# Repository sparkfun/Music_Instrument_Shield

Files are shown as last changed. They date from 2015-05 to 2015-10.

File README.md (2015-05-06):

SparkFun Music Instrument Shield
========================================

SparkFun Music Instrument Shield

[*SparkFun Music Instrument Shield (DEV-10587)*](https://www.sparkfun.com/products/10587)

The SparkFun Musical Instrument Shield is an easy way to add great sounding MIDI sound to your next Arduino project. 
This board is built around the VS1053 MP3 and MIDI codec IC, wired in MIDI mode. 
Simply connect a speaker/stereo/pair of headphones to the 1/8" stereo jack on the shield and pass the proper serial commands to the IC and you’ll be playing music in no time!

Repository Contents
-------------------

* **/Firmware** - Example code 
* **/Hardware** - Eagle design files (.brd, .sch)
* **/Production** - Production panel files (.brd)

Documentation
--------------
* **[Hookup Guide](https://www.sparkfun.com/tutorials/302)** - Basic hookup guide for the Music Instrument Shield.
* **[SparkFun Fritzing repo](https://github.com/sparkfun/Fritzing_Parts)** - Fritzing diagrams for SparkFun products.
* **[SparkFun 3D Model repo](https://github.com/sparkfun/3D_Models)** - 3D models of SparkFun products. 

License Information
-------------------
This product is _**open source**_! 

The **hardware** is released under [Creative Commons ShareAlike 4.0 International](https://creativecommons.org/licenses/by-sa/4.0/).

The **code** is beerware; if you see me (or any other SparkFun employee) at the local, and you've found our code helpful, please buy us a round!

Please use, reuse, and modify these files as you see fit. Please maintain attribution to SparkFun Electronics and release anything derivative under the same license.

Distributed as-is; no warranty is given.

- Your friends at SparkFun.

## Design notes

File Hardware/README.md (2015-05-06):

SparkFun <PRODUCT NAME> Design Files
=====================================

The .sch and .brd files hare are Eagle CAD schematic and PCB design files from SparkFun Electronics.
A freeware version of Eagle can be found [here](http://www.cadsoftusa.com/download-eagle/freeware/). 

License
---------
This product is open source! 
The hardware is released under [Creative Commons ShareAlike 4.0 International](https://creativecommons.org/licenses/by-sa/4.0/).

Please use, reuse, and modify these files as you see fit. Please maintain attribution to SparkFun Electronics and release anything derivative under the same license.

Distributed as-is; no warranty is given.

- Your friends at SparkFun.

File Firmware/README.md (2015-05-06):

SparkFun Music Instrument Firmware
===================================

* **SparkFunMusicInstrument** - Arduino example
    * Demos the MIDI instrument functionality of the Music Instrument Shield.

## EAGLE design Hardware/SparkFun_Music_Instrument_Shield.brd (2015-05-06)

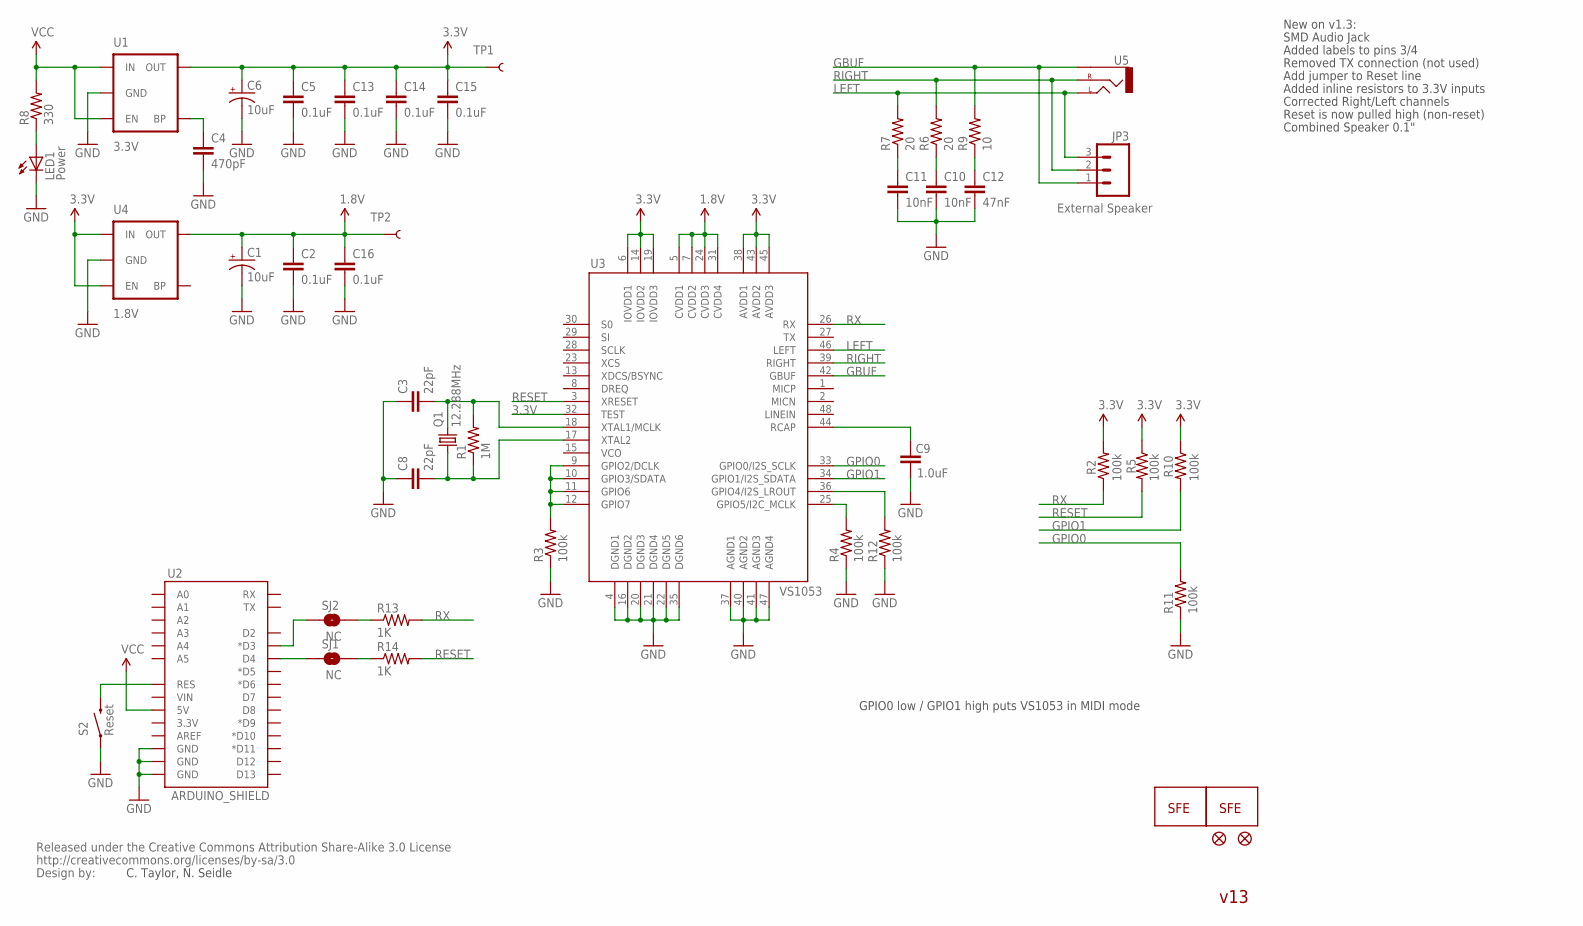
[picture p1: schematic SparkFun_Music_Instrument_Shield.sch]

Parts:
C1, C6: 10uF; EIA3216
C2, C5, C13, C14, C15, C16: 0.1uF; 0402-CAP
C3, C8: 22pF; 0402-CAP
C4: 470pF; 0402-CAP
C9: 1.0uF; 0402-CAP
C10, C11: 10nF; 0402-CAP
C12: 47nF; 0402-CAP
JP3: External Speaker; 1X03
LED1: Power; LED-0603
Q1: 12.288MHz; CRYSTAL-SMD-5X3
R1: 1M; 0402-RES
R2, R3, R4, R5, R10, R11, R12: 100k; 0402-RES
R6, R7: 20; 0402-RES
R8: 330; 0402-RES
R9: 10; 0402-RES
R13, R14: 1K; 0402-RES
S2: Reset; TACTILE_SWITCH_SMD
SJ1, SJ2: NC; SJ_2S-TRACE
TP1, TP2: TEST-POINT3X5; PAD.03X.05
U1: 3.3V; SOT23-5
U2: ARDUINO_SHIELD; DUEMILANOVE_SHIELD
U3: VS1053; LQFP-48
U4: 1.8V; SC70
U5: AUDIO-JACKSMD2; AUDIO-JACK-3.5MM-SMD
U$3: CREATIVE_COMMONS
U$4, U$5: FIDUCIAL1X2; FIDUCIAL-1X2
U$7, U$8: LOGO-SFENEW; SFE-NEW-WEBLOGO

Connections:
1.8V: C1.A (+), C2.1, C16.1, TP2.P$1, U3.5 (CVDD1), U3.7 (CVDD2), U3.24 (CVDD3), U3.31 (CVDD4), U4.5 (OUT)
3.3V: C5.1, C6.A (+), C13.1, C14.1, C15.1, R2.2, R5.1, R10.1, TP1.P$1, U1.5 (OUT), U3.6 (IOVDD1), U3.14 (IOVDD2), U3.19 (IOVDD3), U3.32 (TEST), U3.38 (AVDD1), U3.43 (AVDD2), U3.45 (AVDD3), U4.1 (IN), U4.3 (EN)
ARST: S2.3 (2), U2.RES
G1: R3.2, U3.9 (GPIO2/DCLK), U3.10 (GPIO3/SDATA), U3.11 (GPIO6), U3.12 (GPIO7)
G2: R4.2, U3.25 (GPIO5/I2C_MCLK)
GBUF: JP3.1, R9.2, U3.42 (GBUF), U5.SLEEVE
GND: C1.C (-), C2.2, C3.1, C4.2, C5.2, C6.C (-), C8.1, C9.1, C10.2, C11.2, C12.2, C13.2, C14.2, C15.2, C16.2, LED1.C, R3.1, R4.1, R11.1, R12.1, S2.1, U1.2 (GND), U2.GND@0 (GND), U2.GND@1 (GND), U2.GND@2 (GND), U3.4 (DGND1), U3.16 (DGND2), U3.20 (DGND3), U3.21 (DGND4), U3.22 (DGND5), U3.35 (DGND6), U3.37 (AGND1), U3.40 (AGND2), U3.41 (AGND3), U3.47 (AGND4), U4.2 (GND)
GPIO0: R11.2, U3.33 (GPIO0/I2S_SCLK)
GPIO1: R10.2, U3.34 (GPIO1/I2S_SDATA)
LEFT: JP3.3, R7.2, U3.46 (LEFT), U5.TIP (LEFT)
unnamed: C9.2, U3.44 (RCAP)
unnamed: C12.1, R9.1
unnamed: C10.1, R6.1
unnamed: C11.1, R7.1
unnamed: LED1.A, R8.1
unnamed: SJ1.1, U2.D4
unnamed: R13.1, SJ2.2
unnamed: C3.2, Q1.3 (2), R1.2, U3.18 (XTAL1/MCLK)
unnamed: C8.2, Q1.1, R1.1, U3.17 (XTAL2)
unnamed: R14.1, SJ1.2
unnamed: SJ2.1, U2.D3 (*D3)
unnamed: C4.1, U1.4 (BP)
unnamed: R12.2, U3.36 (GPIO4/I2S_LROUT)
RESET: R5.2, R14.2, U3.3 (XRESET)
RIGHT: JP3.2, R6.2, U3.39 (RIGHT), U5.RING (RIGHT)
RX: R2.1, R13.2, U3.26 (RX)
VCC: R8.2, U1.1 (IN), U1.3 (EN), U2.5V

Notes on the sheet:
GPIO0 low / GPIO1 high puts VS1053 in MIDI mode
C. Taylor, N. Seidle
New on v1.3:
SMD Audio Jack
Added labels to pins 3/4
Removed TX connection (not used)
Add jumper to Reset line
Added inline resistors to 3.3V inputs
Corrected Right/Left channels
Reset is now pulled high (non-reset)
Combined Speaker 0.1"
v13

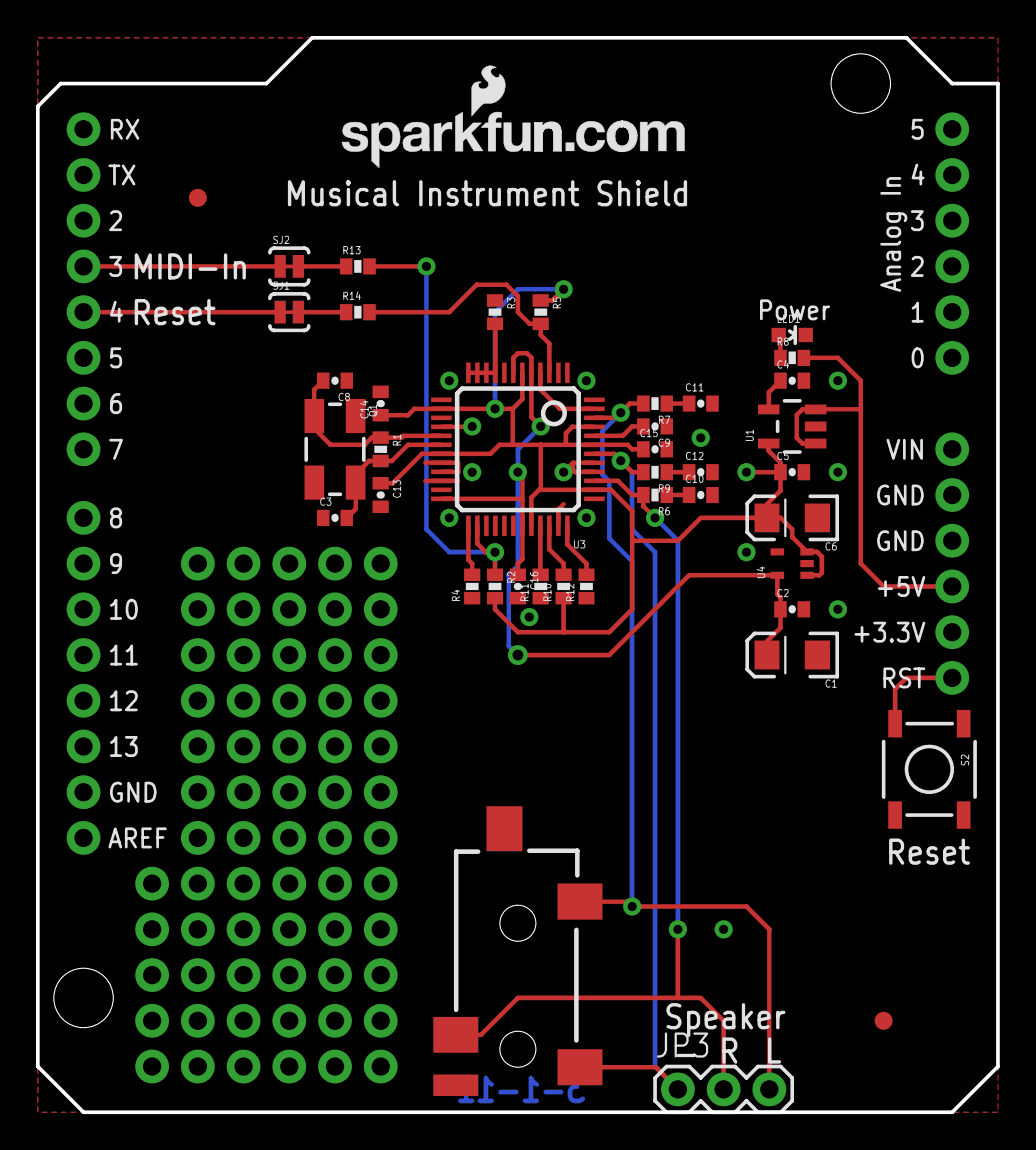
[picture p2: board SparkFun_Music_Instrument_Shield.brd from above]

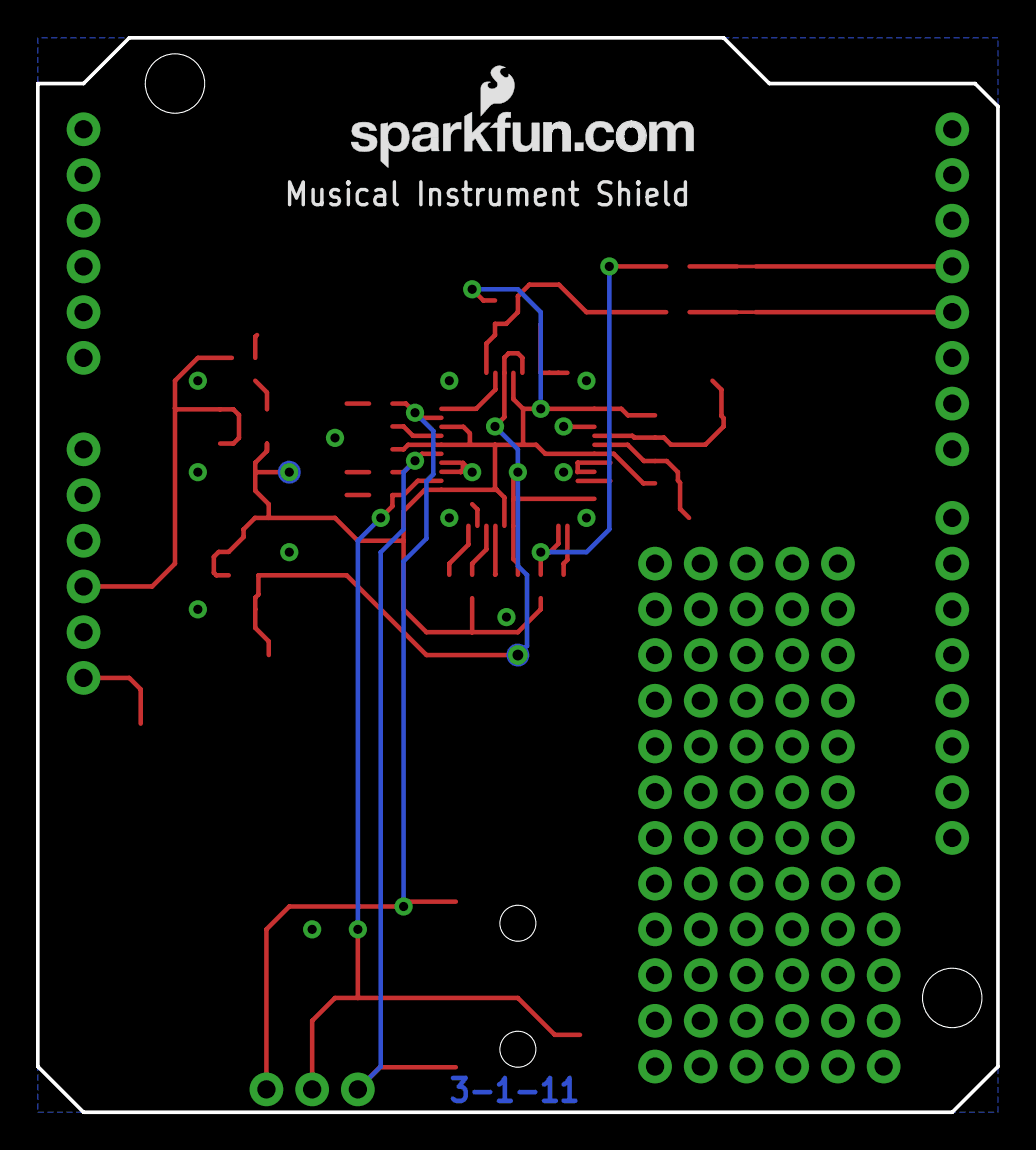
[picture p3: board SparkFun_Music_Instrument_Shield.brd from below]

Board: 2 copper layers, 53.3 x 59.7 mm, 47 parts (3 on the bottom side), 27 nets.

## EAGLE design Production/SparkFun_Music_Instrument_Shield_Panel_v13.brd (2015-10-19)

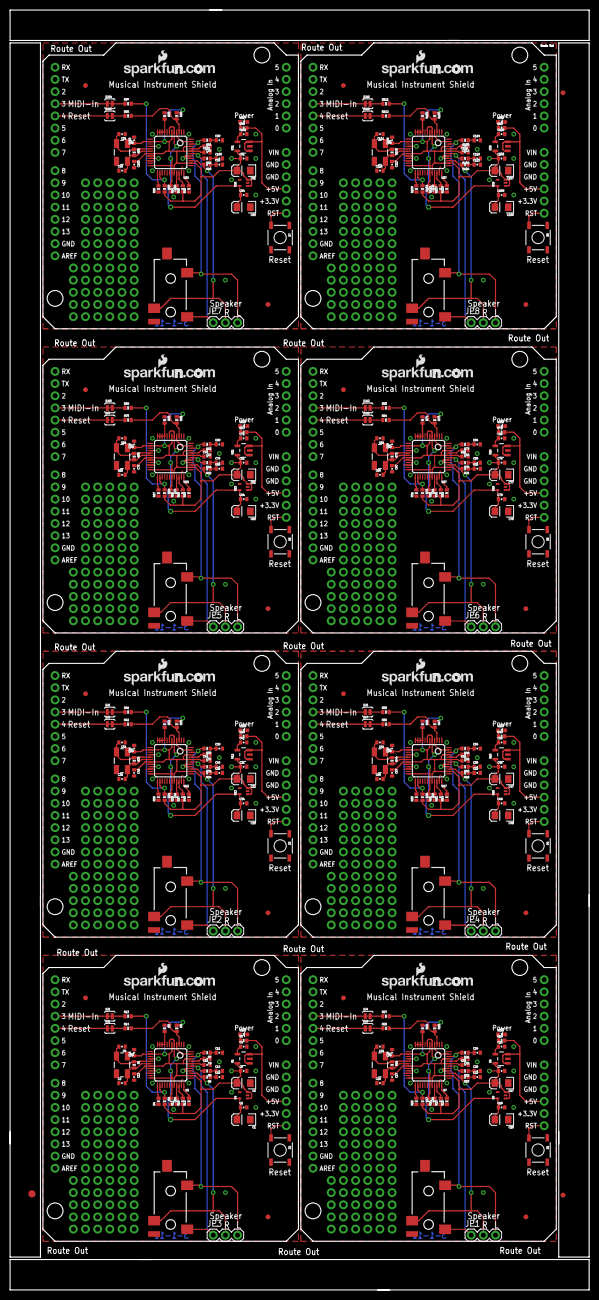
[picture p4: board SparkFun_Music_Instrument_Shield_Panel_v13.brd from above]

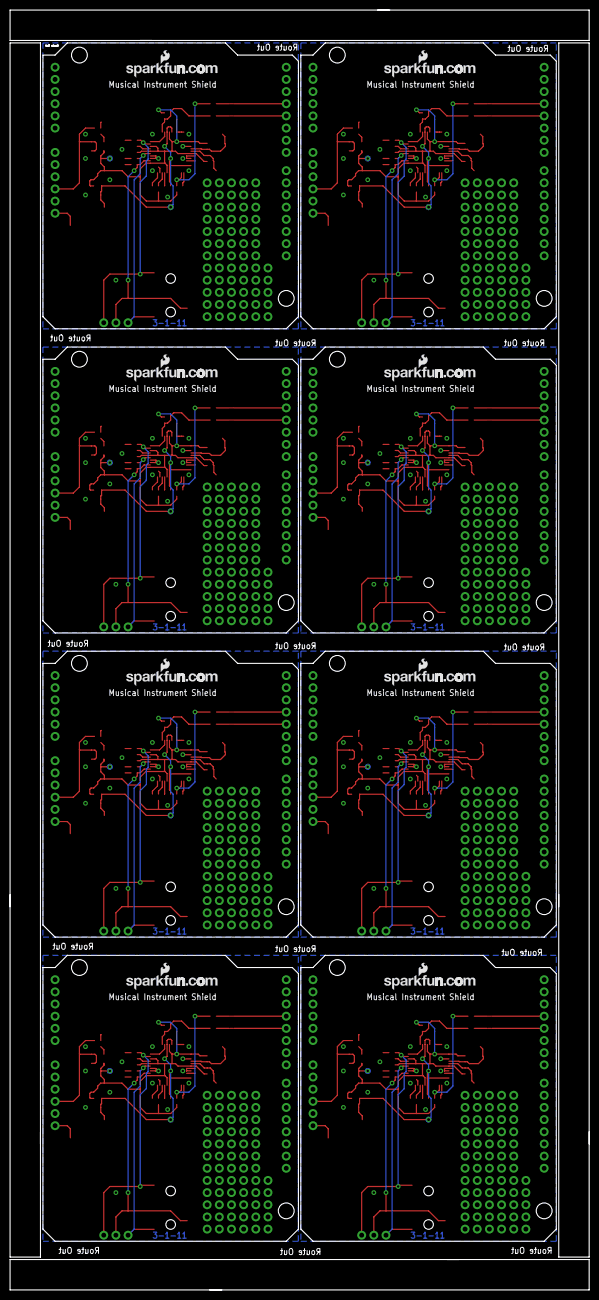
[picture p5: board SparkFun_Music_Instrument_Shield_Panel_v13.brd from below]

Board: 2 copper layers, 120.9 x 267.2 mm, 371 parts (24 on the bottom side), 216 nets.

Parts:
C1, C6, C17, C18, C32, C33, C47, C48, C62, C63, C77, C78, C92, C93, C107, C108: 10uF; EIA3216
C2, C5, C7, C13, C14, C15, C16, C19, C27, C28, C29, C30, C31, C34, C42, C43, C44, C45, C46, C49, C57, C58, C59, C60, C61, C64, C72, C73, C74, C75, C76, C79, C87, C88, C89, C90, C91, C94, C102, C103, C104, C105, C106, C109, C117, C118, C119, C120: 0.1uF; 0402-CAP
C3, C8, C20, C21, C35, C36, C50, C51, C65, C66, C80, C81, C95, C96, C110, C111: 22pF; 0402-CAP
C4, C26, C41, C56, C71, C86, C101, C116: 470pF; 0402-CAP
C9, C22, C37, C52, C67, C82, C97, C112: 1.0uF; 0402-CAP
C10, C11, C23, C24, C38, C39, C53, C54, C68, C69, C83, C84, C98, C99, C113, C114: 10nF; 0402-CAP
C12, C25, C40, C55, C70, C85, C100, C115: 47nF; 0402-CAP
E$1: FIDUCIAL-1.5X3
E$5, E$6: FIDUCIAL-1X2
JP1, JP2, JP3, JP4, JP5, JP6, JP7, JP8: External Speaker; 1X03
LED1, LED2, LED3, LED4, LED5, LED6, LED7, LED8: Power; LED-0603
Q1, Q2, Q3, Q4, Q5, Q6, Q7, Q8: 12.288MHz; CRYSTAL-SMD-5X3
R1, R16, R30, R44, R58, R72, R86, R100: 1M; 0402-RES
R2, R3, R4, R5, R10, R11, R12, R17, R18, R19, R23, R24, R25, R26, R31, R32, R33, R37, R38, R39, R40, R45, R46, R47, R51, R52, R53, R54, R59, R60, R61, R65, R66, R67, R68, R73, R74, R75, R79, R80, R81, R82, R87, R88, R89, R93, R94, R95, R96, R101, R102, R103, R107, R108, R109, R110: 100k; 0402-RES
R6, R7, R20, R21, R34, R35, R48, R49, R62, R63, R76, R77, R90, R91, R104, R105: 20; 0402-RES
R8, R15, R29, R43, R57, R71, R85, R99: 330; 0402-RES
R9, R22, R36, R50, R64, R78, R92, R106: 10; 0402-RES
R13, R14, R27, R28, R41, R42, R55, R56, R69, R70, R83, R84, R97, R98, R111, R112: 1K; 0402-RES
S1, S2, S3, S4, S5, S6, S7, S8: Reset; TACTILE_SWITCH_SMD
SJ1, SJ2, SJ3, SJ4, SJ5, SJ6, SJ7, SJ8, SJ9, SJ10, SJ11, SJ12, SJ13, SJ14, SJ15, SJ16: NC; SJ_2S-TRACE
TP1, TP2, TP3, TP4, TP5, TP6, TP7, TP8, TP9, TP10, TP11, TP12, TP13, TP14, TP15, TP16: PAD.03X.05
U1, U6, U11, U16, U21, U26, U31, U36: 3.3V; SOT23-5
U2, U9, U14, U19, U24, U29, U34, U39: ARDUINO_SHIELD; DUEMILANOVE_SHIELD
U3, U7, U12, U17, U22, U27, U32, U37: VS1053; LQFP-48
U4, U8, U13, U18, U23, U28, U33, U38: 1.8V; SC70
U5, U10, U15, U20, U25, U30, U35, U40: AUDIO-JACK-3.5MM-SMD
U$1, U$6, U$7, U$8, U$9, U$12, U$13, U$16, U$17, U$20, U$21, U$24, U$25, U$28, U$29, U$32: LOGO-SFENEW; SFE-NEW-WEBLOGO
U$2, U$3, U$4, U$5, U$10, U$11, U$14, U$15, U$18, U$19, U$22, U$23, U$26, U$27, U$30, U$31: FIDUCIAL1X2; FIDUCIAL-1X2

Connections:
1.8V: C1.A, C2.1, C16.1, TP2.P$1, U3.5, U3.7, U3.24, U3.31, U4.5
1.8V1: C18.A, C19.1, C30.1, TP4.P$1, U7.5, U7.7, U7.24, U7.31, U8.5
1.8V2: C33.A, C34.1, C45.1, TP6.P$1, U12.5, U12.7, U12.24, U12.31, U13.5
1.8V3: C48.A, C49.1, C60.1, TP8.P$1, U17.5, U17.7, U17.24, U17.31, U18.5
1.8V4: C63.A, C64.1, C75.1, TP10.P$1, U22.5, U22.7, U22.24, U22.31, U23.5
1.8V5: C78.A, C79.1, C90.1, TP12.P$1, U27.5, U27.7, U27.24, U27.31, U28.5
1.8V6: C93.A, C94.1, C105.1, TP14.P$1, U32.5, U32.7, U32.24, U32.31, U33.5
1.8V7: C108.A, C109.1, C120.1, TP16.P$1, U37.5, U37.7, U37.24, U37.31, U38.5
3.3V: C5.1, C6.A, C13.1, C14.1, C15.1, R2.2, R5.1, R10.1, TP1.P$1, U1.5, U3.6, U3.14, U3.19, U3.32, U3.38, U3.43, U3.45, U4.1, U4.3
3.3V1: C7.1, C17.A, C27.1, C28.1, C29.1, R17.2, R19.1, R23.1, TP3.P$1, U6.5, U7.6, U7.14, U7.19, U7.32, U7.38, U7.43, U7.45, U8.1, U8.3
3.3V2: C31.1, C32.A, C42.1, C43.1, C44.1, R31.2, R33.1, R37.1, TP5.P$1, U11.5, U12.6, U12.14, U12.19, U12.32, U12.38, U12.43, U12.45, U13.1, U13.3
3.3V3: C46.1, C47.A, C57.1, C58.1, C59.1, R45.2, R47.1, R51.1, TP7.P$1, U16.5, U17.6, U17.14, U17.19, U17.32, U17.38, U17.43, U17.45, U18.1, U18.3
3.3V4: C61.1, C62.A, C72.1, C73.1, C74.1, R59.2, R61.1, R65.1, TP9.P$1, U21.5, U22.6, U22.14, U22.19, U22.32, U22.38, U22.43, U22.45, U23.1, U23.3
3.3V5: C76.1, C77.A, C87.1, C88.1, C89.1, R73.2, R75.1, R79.1, TP11.P$1, U26.5, U27.6, U27.14, U27.19, U27.32, U27.38, U27.43, U27.45, U28.1, U28.3
3.3V6: C91.1, C92.A, C102.1, C103.1, C104.1, R87.2, R89.1, R93.1, TP13.P$1, U31.5, U32.6, U32.14, U32.19, U32.32, U32.38, U32.43, U32.45, U33.1, U33.3
3.3V7: C106.1, C107.A, C117.1, C118.1, C119.1, R101.2, R103.1, R107.1, TP15.P$1, U36.5, U37.6, U37.14, U37.19, U37.32, U37.38, U37.43, U37.45, U38.1, U38.3
ARST: S2.3, U2.RES
ARST1: S1.3, U9.RES
ARST2: S3.3, U14.RES
ARST3: S4.3, U19.RES
ARST4: S5.3, U24.RES
ARST5: S6.3, U29.RES
ARST6: S7.3, U34.RES
ARST7: S8.3, U39.RES
G1: R3.2, U3.9, U3.10, U3.11, U3.12
G2: R4.2, U3.25
G3: R18.2, U7.9, U7.10, U7.11, U7.12
G4: R25.2, U7.25
G5: R32.2, U12.9, U12.10, U12.11, U12.12
G6: R39.2, U12.25
G7: R46.2, U17.9, U17.10, U17.11, U17.12
G8: R53.2, U17.25
G9: R60.2, U22.9, U22.10, U22.11, U22.12
G10: R67.2, U22.25
G11: R74.2, U27.9, U27.10, U27.11, U27.12
G12: R81.2, U27.25
G13: R88.2, U32.9, U32.10, U32.11, U32.12
G14: R95.2, U32.25
G15: R102.2, U37.9, U37.10, U37.11, U37.12
G16: R109.2, U37.25
GBUF: JP3.1, R9.2, U3.42, U5.SLEEVE
GBUF1: JP1.1, R22.2, U7.42, U10.SLEEVE
GBUF2: JP2.1, R36.2, U12.42, U15.SLEEVE
GBUF3: JP4.1, R50.2, U17.42, U20.SLEEVE
GBUF4: JP5.1, R64.2, U22.42, U25.SLEEVE
GBUF5: JP6.1, R78.2, U27.42, U30.SLEEVE
GBUF6: JP7.1, R92.2, U32.42, U35.SLEEVE
GBUF7: JP8.1, R106.2, U37.42, U40.SLEEVE
GND: C1.C, C2.2, C3.1, C4.2, C5.2, C6.C, C8.1, C9.1, C10.2, C11.2, C12.2, C13.2, C14.2, C15.2, C16.2, LED1.C, R3.1, R4.1, R11.1, R12.1, S2.1, U1.2, U2.GND@0, U2.GND@1, U2.GND@2, U3.4, U3.16, U3.20, U3.21, U3.22, U3.35, U3.37, U3.40, U3.41, U3.47, U4.2
GND1: C7.2, C17.C, C18.C, C19.2, C20.1, C21.1, C22.1, C23.2, C24.2, C25.2, C26.2, C27.2, C28.2, C29.2, C30.2, LED2.C, R18.1, R24.1, R25.1, R26.1, S1.1, U6.2, U7.4, U7.16, U7.20, U7.21, U7.22, U7.35, U7.37, U7.40, U7.41, U7.47, U8.2, U9.GND@0, U9.GND@1, U9.GND@2
GND2: C31.2, C32.C, C33.C, C34.2, C35.1, C36.1, C37.1, C38.2, C39.2, C40.2, C41.2, C42.2, C43.2, C44.2, C45.2, LED3.C, R32.1, R38.1, R39.1, R40.1, S3.1, U11.2, U12.4, U12.16, U12.20, U12.21, U12.22, U12.35, U12.37, U12.40, U12.41, U12.47, U13.2, U14.GND@0, U14.GND@1, U14.GND@2
GND3: C46.2, C47.C, C48.C, C49.2, C50.1, C51.1, C52.1, C53.2, C54.2, C55.2, C56.2, C57.2, C58.2, C59.2, C60.2, LED4.C, R46.1, R52.1, R53.1, R54.1, S4.1, U16.2, U17.4, U17.16, U17.20, U17.21, U17.22, U17.35, U17.37, U17.40, U17.41, U17.47, U18.2, U19.GND@0, U19.GND@1, U19.GND@2
GND4: C61.2, C62.C, C63.C, C64.2, C65.1, C66.1, C67.1, C68.2, C69.2, C70.2, C71.2, C72.2, C73.2, C74.2, C75.2, LED5.C, R60.1, R66.1, R67.1, R68.1, S5.1, U21.2, U22.4, U22.16, U22.20, U22.21, U22.22, U22.35, U22.37, U22.40, U22.41, U22.47, U23.2, U24.GND@0, U24.GND@1, U24.GND@2
GND5: C76.2, C77.C, C78.C, C79.2, C80.1, C81.1, C82.1, C83.2, C84.2, C85.2, C86.2, C87.2, C88.2, C89.2, C90.2, LED6.C, R74.1, R80.1, R81.1, R82.1, S6.1, U26.2, U27.4, U27.16, U27.20, U27.21, U27.22, U27.35, U27.37, U27.40, U27.41, U27.47, U28.2, U29.GND@0, U29.GND@1, U29.GND@2
GND6: C91.2, C92.C, C93.C, C94.2, C95.1, C96.1, C97.1, C98.2, C99.2, C100.2, C101.2, C102.2, C103.2, C104.2, C105.2, LED7.C, R88.1, R94.1, R95.1, R96.1, S7.1, U31.2, U32.4, U32.16, U32.20, U32.21, U32.22, U32.35, U32.37, U32.40, U32.41, U32.47, U33.2, U34.GND@0, U34.GND@1, U34.GND@2
GND7: C106.2, C107.C, C108.C, C109.2, C110.1, C111.1, C112.1, C113.2, C114.2, C115.2, C116.2, C117.2, C118.2, C119.2, C120.2, LED8.C, R102.1, R108.1, R109.1, R110.1, S8.1, U36.2, U37.4, U37.16, U37.20, U37.21, U37.22, U37.35, U37.37, U37.40, U37.41, U37.47, U38.2, U39.GND@0, U39.GND@1, U39.GND@2
GPIO0: R11.2, U3.33
GPIO1: R10.2, U3.34
GPIO2: R24.2, U7.33
GPIO3: R23.2, U7.34
GPIO4: R38.2, U12.33
GPIO5: R37.2, U12.34
GPIO6: R52.2, U17.33
GPIO7: R51.2, U17.34
GPIO8: R66.2, U22.33
GPIO9: R65.2, U22.34
GPIO10: R80.2, U27.33
GPIO11: R79.2, U27.34
GPIO12: R94.2, U32.33
GPIO13: R93.2, U32.34
GPIO14: R108.2, U37.33
GPIO15: R107.2, U37.34
LEFT: JP3.3, R7.2, U3.46, U5.TIP
LEFT1: JP1.3, R21.2, U7.46, U10.TIP
LEFT2: JP2.3, R35.2, U12.46, U15.TIP
LEFT3: JP4.3, R49.2, U17.46, U20.TIP
LEFT4: JP5.3, R63.2, U22.46, U25.TIP
LEFT5: JP6.3, R77.2, U27.46, U30.TIP
LEFT6: JP7.3, R91.2, U32.46, U35.TIP
LEFT7: JP8.3, R105.2, U37.46, U40.TIP
unnamed: C9.2, U3.44
unnamed: C12.1, R9.1
unnamed: C10.1, R6.1
unnamed: C11.1, R7.1
unnamed: LED1.A, R8.1
unnamed: SJ1.1, U2.D4
unnamed: R13.1, SJ2.2
unnamed: C3.2, Q1.3, R1.2, U3.18
unnamed: C8.2, Q1.1, R1.1, U3.17
unnamed: R14.1, SJ1.2
unnamed: LED2.A, R15.1
unnamed: SJ2.1, U2.D3
unnamed: C20.2, Q2.3, R16.2, U7.18
unnamed: C21.2, Q2.1, R16.1, U7.17
unnamed: C22.2, U7.44
unnamed: C25.1, R22.1
unnamed: C24.1, R21.1
unnamed: C23.1, R20.1
unnamed: C4.1, U1.4
unnamed: R12.2, U3.36
unnamed: C26.1, U6.4
unnamed: R26.2, U7.36
unnamed: SJ3.1, U9.D4
unnamed: R28.1, SJ3.2
unnamed: SJ4.1, U9.D3
unnamed: R27.1, SJ4.2
unnamed: LED3.A, R29.1
unnamed: C35.2, Q3.3, R30.2, U12.18
unnamed: C36.2, Q3.1, R30.1, U12.17
unnamed: C37.2, U12.44
unnamed: C40.1, R36.1
unnamed: C39.1, R35.1
unnamed: C38.1, R34.1
unnamed: C41.1, U11.4
unnamed: R40.2, U12.36
unnamed: SJ5.1, U14.D4
unnamed: R42.1, SJ5.2
unnamed: SJ6.1, U14.D3
unnamed: R41.1, SJ6.2
unnamed: LED4.A, R43.1
unnamed: C50.2, Q4.3, R44.2, U17.18
unnamed: C51.2, Q4.1, R44.1, U17.17
unnamed: C52.2, U17.44
unnamed: C55.1, R50.1
unnamed: C54.1, R49.1
unnamed: C53.1, R48.1
unnamed: C56.1, U16.4
unnamed: R54.2, U17.36
unnamed: SJ7.1, U19.D4
unnamed: R56.1, SJ7.2
unnamed: SJ8.1, U19.D3
unnamed: R55.1, SJ8.2
unnamed: LED5.A, R57.1
unnamed: C65.2, Q5.3, R58.2, U22.18
unnamed: C66.2, Q5.1, R58.1, U22.17
unnamed: C67.2, U22.44
unnamed: C70.1, R64.1
unnamed: C69.1, R63.1
unnamed: C68.1, R62.1
unnamed: C71.1, U21.4
unnamed: R68.2, U22.36
unnamed: SJ9.1, U24.D4
unnamed: R70.1, SJ9.2
unnamed: SJ10.1, U24.D3
unnamed: R69.1, SJ10.2
unnamed: LED6.A, R71.1
unnamed: C80.2, Q6.3, R72.2, U27.18
unnamed: C81.2, Q6.1, R72.1, U27.17
unnamed: C82.2, U27.44
unnamed: C85.1, R78.1
unnamed: C84.1, R77.1
unnamed: C83.1, R76.1
unnamed: C86.1, U26.4
unnamed: R82.2, U27.36
unnamed: SJ11.1, U29.D4
unnamed: R84.1, SJ11.2
unnamed: SJ12.1, U29.D3
unnamed: R83.1, SJ12.2
unnamed: LED7.A, R85.1
unnamed: C95.2, Q7.3, R86.2, U32.18
unnamed: C96.2, Q7.1, R86.1, U32.17
unnamed: C97.2, U32.44
unnamed: C100.1, R92.1
unnamed: C99.1, R91.1
unnamed: C98.1, R90.1
unnamed: C101.1, U31.4
unnamed: R96.2, U32.36
unnamed: SJ13.1, U34.D4
unnamed: R98.1, SJ13.2
unnamed: SJ14.1, U34.D3
unnamed: R97.1, SJ14.2
unnamed: LED8.A, R99.1
unnamed: C110.2, Q8.3, R100.2, U37.18
unnamed: C111.2, Q8.1, R100.1, U37.17
unnamed: C112.2, U37.44
unnamed: C115.1, R106.1
unnamed: C114.1, R105.1
unnamed: C113.1, R104.1
unnamed: C116.1, U36.4
unnamed: R110.2, U37.36
unnamed: SJ15.1, U39.D4
unnamed: R112.1, SJ15.2
unnamed: SJ16.1, U39.D3
unnamed: R111.1, SJ16.2
RESET: R5.2, R14.2, U3.3
RESET1: R19.2, R28.2, U7.3
RESET2: R33.2, R42.2, U12.3
RESET3: R47.2, R56.2, U17.3
RESET4: R61.2, R70.2, U22.3
RESET5: R75.2, R84.2, U27.3
RESET6: R89.2, R98.2, U32.3
RESET7: R103.2, R112.2, U37.3
RIGHT: JP3.2, R6.2, U3.39, U5.RING
RIGHT1: JP1.2, R20.2, U7.39, U10.RING
RIGHT2: JP2.2, R34.2, U12.39, U15.RING
RIGHT3: JP4.2, R48.2, U17.39, U20.RING
RIGHT4: JP5.2, R62.2, U22.39, U25.RING
RIGHT5: JP6.2, R76.2, U27.39, U30.RING
RIGHT6: JP7.2, R90.2, U32.39, U35.RING
RIGHT7: JP8.2, R104.2, U37.39, U40.RING
RX: R2.1, R13.2, U3.26
RX1: R17.1, R27.2, U7.26
RX2: R31.1, R41.2, U12.26
RX3: R45.1, R55.2, U17.26
RX4: R59.1, R69.2, U22.26
RX5: R73.1, R83.2, U27.26
RX6: R87.1, R97.2, U32.26
RX7: R101.1, R111.2, U37.26
VCC: R8.2, U1.1, U1.3, U2.5V
VCC1: R15.2, U6.1, U6.3, U9.5V
VCC2: R29.2, U11.1, U11.3, U14.5V
VCC3: R43.2, U16.1, U16.3, U19.5V
VCC4: R57.2, U21.1, U21.3, U24.5V
VCC5: R71.2, U26.1, U26.3, U29.5V
VCC6: R85.2, U31.1, U31.3, U34.5V
VCC7: R99.2, U36.1, U36.3, U39.5V

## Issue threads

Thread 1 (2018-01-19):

FRDM KL25Z

badabin, 2018-01-19:
Disclaimer: am an absolute beginner, pardon my misconceptions and assumptions.
I wanted to hookup the musical instrument shield to my kl25z board, Is it possible?

badabin, 2018-01-22:
``

Grahldg, 2018-08-06:
Hello, thanks for your question.  It appears that the KL25Z was designed for compatibility with Arduino shields so I would assume it should work, but that is not a product we carry so I'm not able to guarantee compatibility.  If you decide to try it and run into problems you can always contact our [Technical Assistance Team](https://www.sparkfun.com/technical_assistance) for more immediate help.

Closed 2018-09-07.

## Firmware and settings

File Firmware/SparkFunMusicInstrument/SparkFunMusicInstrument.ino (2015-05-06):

/*
 2-12-2011
 Spark Fun Electronics 2011
 Nathan Seidle
 Updated to Arduino 1.01 by Marc "Trench" Tschudin
 
 This code is public domain but you buy me a beer if you use this and we meet someday (Beerware license).
 
 This code works with the VS1053 Breakout Board and controls the VS1053 in what is called Real Time MIDI mode. 
 To get the VS1053 into RT MIDI mode, power up the VS1053 breakout board with GPIO0 tied low, GPIO1 tied high.
 
 I use the NewSoftSerial library to send out the MIDI serial at 31250bps. This allows me to print regular messages
 for debugging to the terminal window. This helped me out a ton.
 
 5V : VS1053 VCC
 GND : VS1053 GND
 D3 (SoftSerial TX) : VS1053 RX
 D4 : VS1053 RESET
 
 Attach a headphone breakout board to the VS1053:
 VS1053 LEFT : TSH
 VS1053 RIGHT : RSH
 VS1053 GBUF : GND
 
 When in the drum bank (0x78), there are not different instruments, only different notes.
 To play the different sounds, select an instrument # like 5, then play notes 27 to 87.
 
 To play "Sticks" (31):
 talkMIDI(0xB0, 0, 0x78); //Bank select: drums
 talkMIDI(0xC0, 5, 0); //Set instrument number
 //Play note on channel 1 (0x90), some note value (note), middle velocity (60):
 noteOn(0, 31, 60);
 
 */

#include <SoftwareSerial.h>

SoftwareSerial mySerial(2, 3); // RX, TX

byte note = 0; //The MIDI note value to be played
byte resetMIDI = 4; //Tied to VS1053 Reset line
byte ledPin = 13; //MIDI traffic inidicator
int  instrument = 0;

void setup() {
  Serial.begin(57600);

  //Setup soft serial for MIDI control
  mySerial.begin(31250);

  //Reset the VS1053
  pinMode(resetMIDI, OUTPUT);
  digitalWrite(resetMIDI, LOW);
  delay(100);
  digitalWrite(resetMIDI, HIGH);
  delay(100);
  talkMIDI(0xB0, 0x07, 120); //0xB0 is channel message, set channel volume to near max (127)
}

void loop() {




  //Demo Basic MIDI instruments, GM1
  //=================================================================
  Serial.println("Basic Instruments");
  talkMIDI(0xB0, 0, 0x00); //Default bank GM1

  //Change to different instrument
  for(instrument = 0 ; instrument < 127 ; instrument++) {

    Serial.print(" Instrument: ");
    Serial.println(instrument, DEC);

    talkMIDI(0xC0, instrument, 0); //Set instrument number. 0xC0 is a 1 data byte command

    //Play notes from F#-0 (30) to F#-5 (90):
    for (note = 30 ; note < 40 ; note++) {
      Serial.print("N:");
      Serial.println(note, DEC);
      
      //Note on channel 1 (0x90), some note value (note), middle velocity (0x45):
      noteOn(0, note, 60);
      delay(50);

      //Turn off the note with a given off/release velocity
      noteOff(0, note, 60);
      delay(50);
    }

    delay(100); //Delay between instruments
  }
  //=================================================================



/*
  //Demo GM2 / Fancy sounds
  //=================================================================
  Serial.println("Demo Fancy Sounds");
  talkMIDI(0xB0, 0, 0x78); //Bank select drums

  //For this bank 0x78, the instrument does not matter, only the note
  for(instrument = 30 ; instrument < 31 ; instrument++) {

    Serial.print(" Instrument: ");
    Serial.println(instrument, DEC);

    talkMIDI(0xC0, instrument, 0); //Set instrument number. 0xC0 is a 1 data byte command

    //Play fancy sounds from 'High Q' to 'Open Surdo [EXC 6]'
    for (note = 27 ; note < 87 ; note++) {
      Serial.print("N:");
      Serial.println(note, DEC);
      
      //Note on channel 1 (0x90), some note value (note), middle velocity (0x45):
      noteOn(0, note, 60);
      delay(100);

      //Turn off the note with a given off/release velocity
      noteOff(0, note, 60);
      delay(100);
    }

    delay(100); //Delay between instruments
  }
*/


/*
  //Demo Melodic
  //=================================================================
  Serial.println("Demo Melodic? Sounds");
  talkMIDI(0xB0, 0, 0x79); //Bank select Melodic
  //These don't sound different from the main bank to me

  //Change to different instrument
  for(instrument = 27 ; instrument < 87 ; instrument++) {

    Serial.print(" Instrument: ");
    Serial.println(instrument, DEC);

    talkMIDI(0xC0, instrument, 0); //Set instrument number. 0xC0 is a 1 data byte command

    //Play notes from F#-0 (30) to F#-5 (90):
    for (note = 30 ; note < 40 ; note++) {
      Serial.print("N:");
      Serial.println(note, DEC);
      
      //Note on channel 1 (0x90), some note value (note), middle velocity (0x45):
      noteOn(0, note, 60);
      delay(50);

      //Turn off the note with a given off/release velocity
      noteOff(0, note, 60);
      delay(50);
    }

    delay(100); //Delay between instruments
  }
*/


}

//Send a MIDI note-on message.  Like pressing a piano key
//channel ranges from 0-15
void noteOn(byte channel, byte note, byte attack_velocity) {
  talkMIDI( (0x90 | channel), note, attack_velocity);
}

//Send a MIDI note-off message.  Like releasing a piano key
void noteOff(byte channel, byte note, byte release_velocity) {
  talkMIDI( (0x80 | channel), note, release_velocity);
}

//Plays a MIDI note. Doesn't check to see that cmd is greater than 127, or that data values are less than 127
void talkMIDI(byte cmd, byte data1, byte data2) {
  digitalWrite(ledPin, HIGH);
  mySerial.write(cmd);
  mySerial.write(data1);

  //Some commands only have one data byte. All cmds less than 0xBn have 2 data bytes 
  //(sort of: http://253.ccarh.org/handout/midiprotocol/)
  if( (cmd & 0xF0) <= 0xB0)
    mySerial.write(data2);

  digitalWrite(ledPin, LOW);
}

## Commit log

2015-05-06 Adding hardware, demo sketch, readme links
    [SparkFun_Music_Instrument_Shield.brd, SparkFun_Music_Instrument_Shield.sch]
2015-10-19 created panel v13
    [SparkFun_Music_Instrument_Shield_Panel_v13.brd]

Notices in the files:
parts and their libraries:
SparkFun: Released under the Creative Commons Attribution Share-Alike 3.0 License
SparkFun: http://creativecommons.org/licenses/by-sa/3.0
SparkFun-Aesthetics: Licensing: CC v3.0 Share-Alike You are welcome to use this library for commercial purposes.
